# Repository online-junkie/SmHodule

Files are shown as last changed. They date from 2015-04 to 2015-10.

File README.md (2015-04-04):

# SmHodule

SmHodule is using the Wifi SoC ESP8266, the ESP8266 is a System on Chip and is as powerful as an Arduino.

SmHodule = Smart Home module for the Internet of Things.

This module is based on a set of examples found in the Internet about ESP8266 and implementing a actor, sender, sensor and I2C OLED.

The Setup data is cached in the modules flash memory.

Feel free to expand SmHodule and add your own ideas.

## Compile

Compile the code, then: make clean, make html, make all, make flashall
 
For first time setup keep GPIO15 pulled to ground for 35 seconds.
After first time configuration the module reboots and starts as an Access Point. Connect your wifi network to the new AP and use the default AP IP: 192.168.4.1 in your browser to access the module. Note: Your local router has to be DHCP enabled.

The device MAC and also the IP the module receives is shown on the SmHodule setup page. Make this IP static DHCP by using the modules name as the device name for your DHCP configuration.

Enjoy

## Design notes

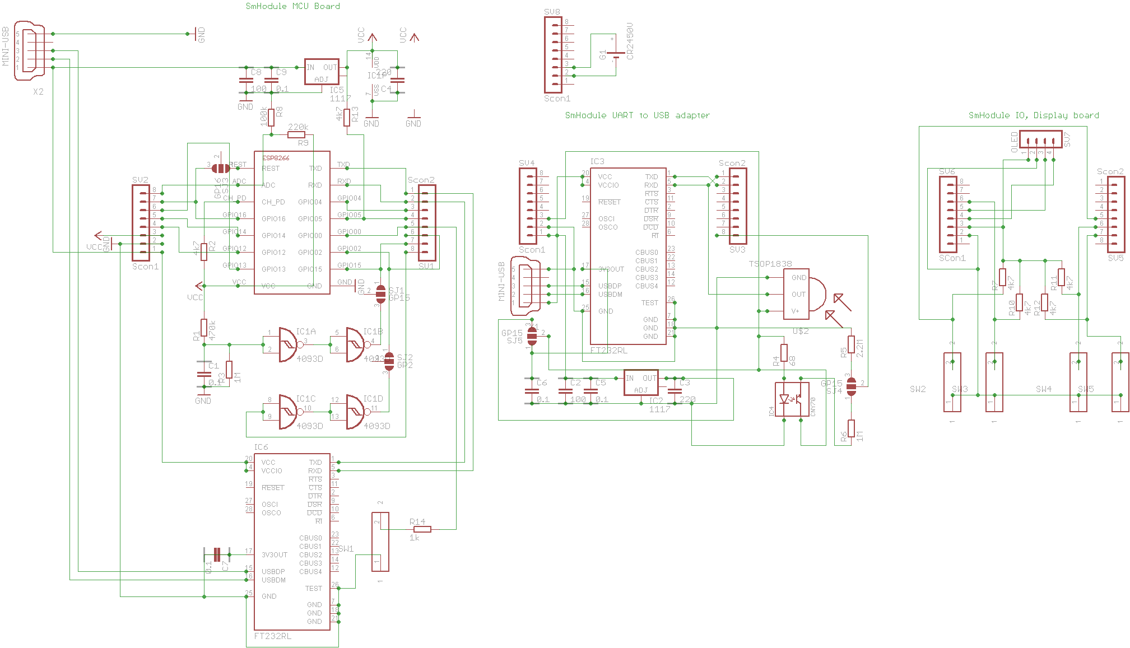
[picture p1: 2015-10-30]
SmHodule/SmHodule-Schematic.png

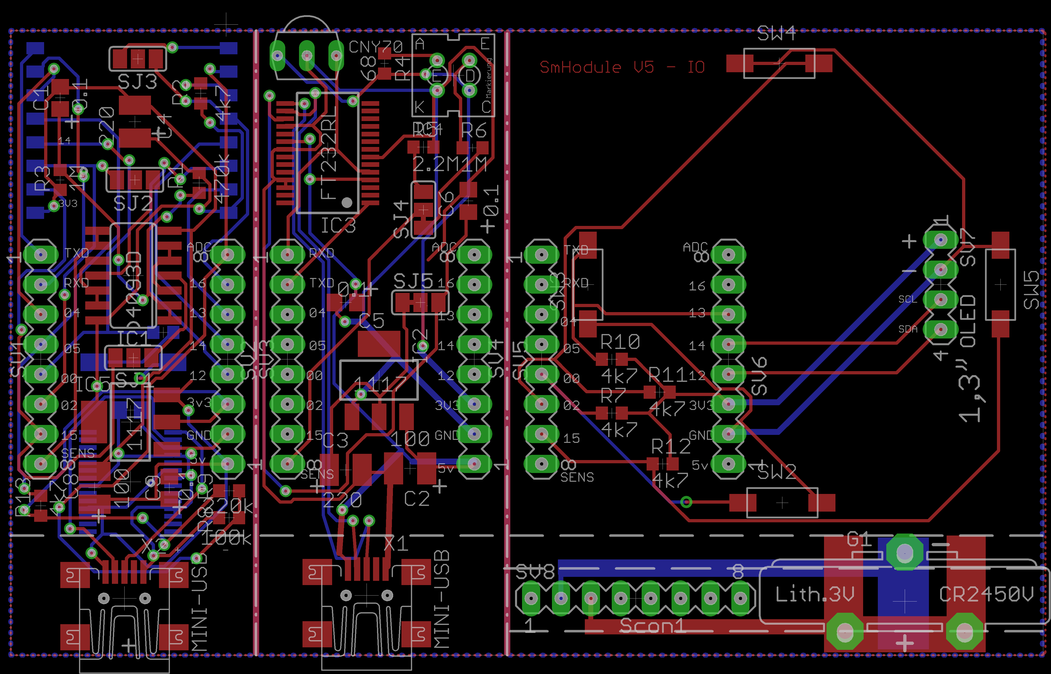
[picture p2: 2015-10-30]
SmHodule/SmHodule.png

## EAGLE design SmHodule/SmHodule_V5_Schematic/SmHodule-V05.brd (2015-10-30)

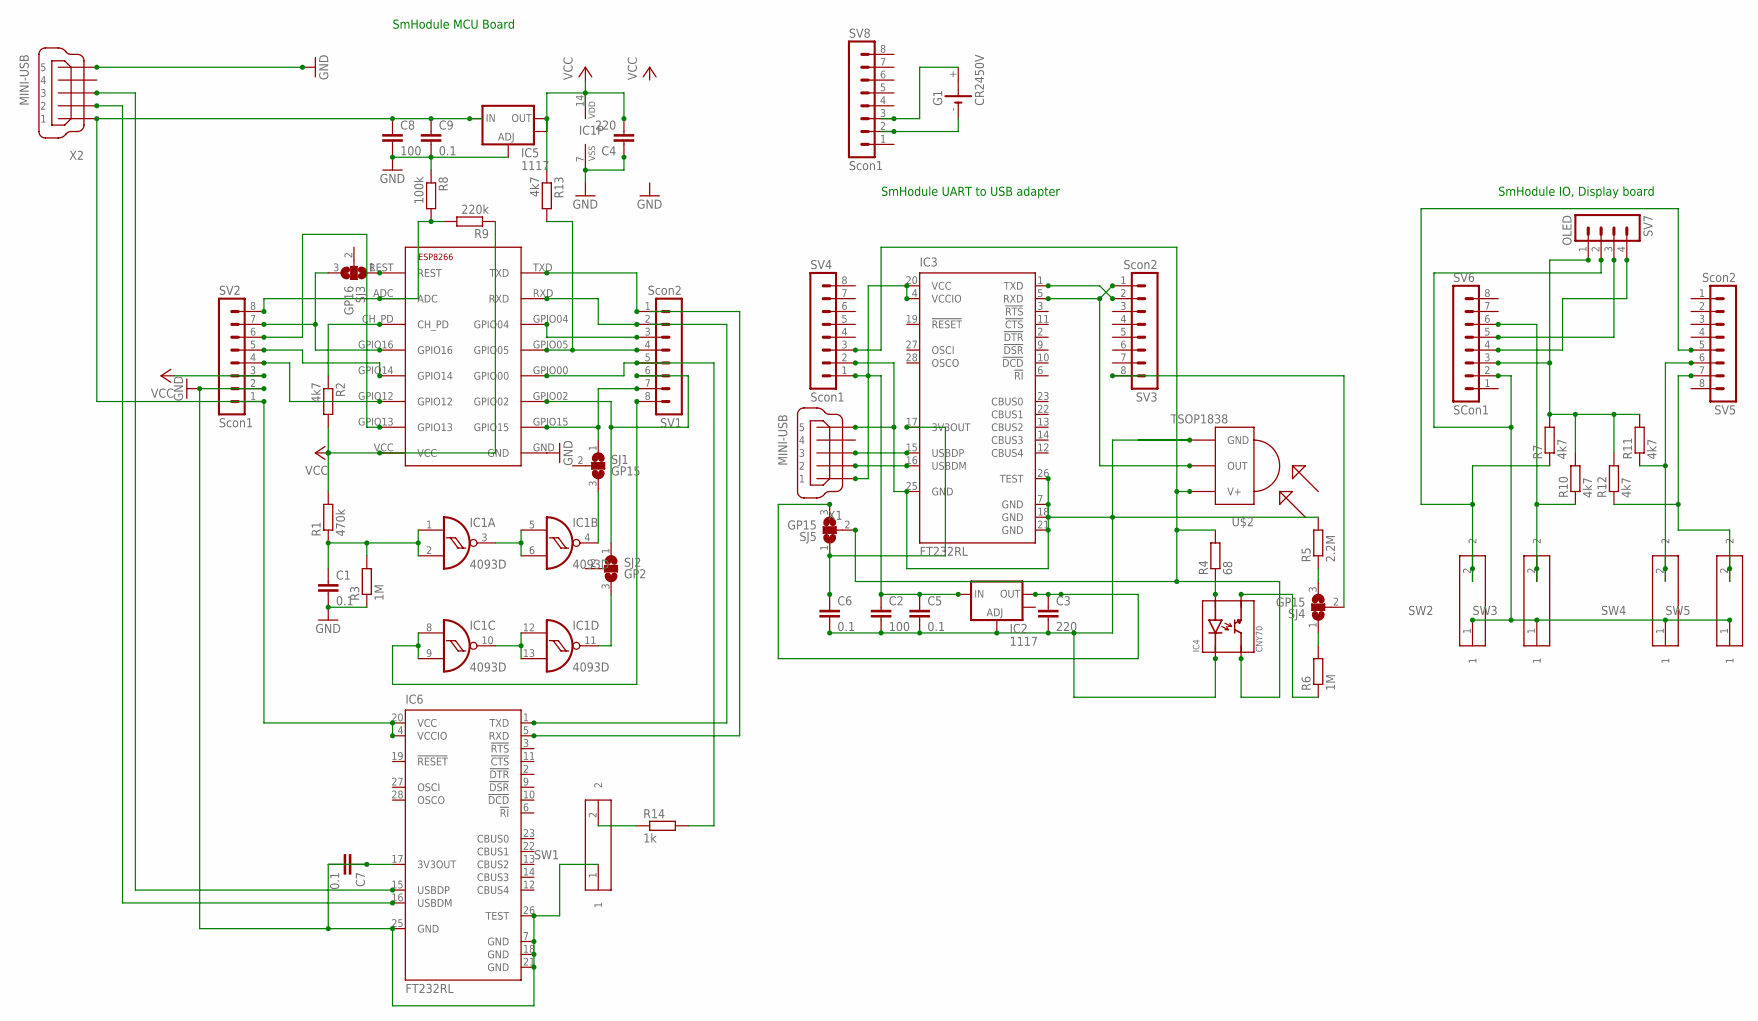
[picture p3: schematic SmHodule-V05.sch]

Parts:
C1, C5, C6, C7, C9: 0.1; C0805
C2, C8: 100; C1210
C3, C4: 220; C1210
G1: CR2450V
IC1: 4093D; SO14
IC2, IC5: 1117; SOT223
IC3, IC6: FT232RL; SSOP28
IC4: CNY70
R1: 470k; R0603
R2, R7, R10, R11, R12, R13: 4k7; R0603
R3, R6: 1M; R0603
R4: 68; R0603
R5: 2.2M; R0603
R8: 100k; R0603
R9: 220k; R0603
R14: 1k; R0603
SJ1, SJ4, SJ5: GP15; SJ_2
SJ2: GP2; SJ_2
SJ3: GP16; SJ_2
SV1, SV3, SV5: Scon2; MA08-1
SV2, SV4, SV8: Scon1; MA08-1
SV6: SCon1; MA08-1
SV7: OLED; MA04-1
SW1, SW2, SW3, SW4, SW5: 434111043826
U$1: ESP1; ESP-12
U$2: TSOP1838; TSOP18XX
X1, X2: MINI-USB; UX60-MB-5ST

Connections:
GND: C1.2, C4.1, C7.2, C8.2, C9.2, IC1.7 (VSS), IC5.1 (ADJ), IC6.7 (GND), IC6.18 (GND), IC6.21 (GND), IC6.25 (GND), IC6.26 (TEST), R3.1, R8.1, SV2.2, SW1.1, U$1.GND, X2.5
unnamed: C1.1, IC1.1 (I0), IC1.2 (I1), R1.1, R3.2
unnamed: IC1.3 (O), IC1.5 (I0), IC1.6 (I1)
unnamed: IC3.1 (TXD), SV3.2
unnamed: IC1.10 (O), IC1.12 (I0), IC1.13 (I1)
unnamed: IC1.4 (O), SJ1.3
unnamed: SV1.1, U$1.TXD
unnamed: SV1.2, U$1.RXD
unnamed: SV2.6, U$1.GPIO13
unnamed: R14.2, SV1.5, U$1.GPIO00
unnamed: SV2.4, U$1.GPIO12
unnamed: SV2.5, U$1.GPIO14
unnamed: SV1.3, U$1.GPIO04
unnamed: R13.2, SV1.4, U$1.GPIO05
unnamed: SJ3.3, SV2.7, U$1.GPIO16
unnamed: R6.2, SJ4.1
unnamed: R8.2, R9.2, SV2.8, U$1.ADC
unnamed: R2.1, U$1.CH_PD
unnamed: SJ1.1, SV1.7, U$1.GPIO15
unnamed: IC3.5 (RXD), SV3.1, U$2.OUT
unnamed: C2.2, C3.2, C5.2, C6.2, IC2.1 (ADJ), IC3.7 (GND), IC3.18 (GND), IC3.21 (GND), IC3.25 (GND), IC3.26 (TEST), IC4.EK, R5.2, SV4.2, U$2.GND, X1.5
unnamed: IC1.11 (O), SJ2.3
unnamed: SJ2.1, SV1.6, U$1.GPIO02
unnamed: SJ3.1, U$1.REST
unnamed: IC1.8 (I0), IC1.9 (I1), SV1.8
unnamed: IC4.DC, R4.2, SJ5.2, SV4.3, U$2.VCC (V+)
unnamed: C2.1, C5.1, IC2.3 (IN), IC3.4 (VCCIO), IC3.20 (VCC), SV4.1, X1.1
unnamed: R7.2, R10.2, R11.2, R12.2, SV6.3, SV7.1
unnamed: R11.1, SV5.6, SW4.2
unnamed: IC4.DE, R6.1
unnamed: R5.1, SJ4.3
unnamed: SV6.5, SV7.3
unnamed: R10.1, SV6.6, SW3.2
unnamed: R14.1, SW1.2
unnamed: IC4.EA, R4.1
unnamed: IC3.16 (USBDM), X1.2
unnamed: IC3.15 (USBDP), X1.3
unnamed: C6.1, IC3.17 (3V3OUT), SJ5.1
unnamed: R7.1, SV5.5, SW2.2
unnamed: SV6.4, SV7.4
unnamed: R12.1, SV5.7, SW5.2
unnamed: C3.1, IC2.2 (OUT), SJ5.3
unnamed: SV6.2, SV7.2, SW2.1, SW3.1, SW4.1, SW5.1
unnamed: SJ4.2, SV3.8
unnamed: G1.-, SV8.2
unnamed: G1.+, SV8.3
unnamed: C8.1, C9.1, IC5.3 (IN), IC6.4 (VCCIO), IC6.20 (VCC), SV2.1, X2.1
unnamed: IC6.15 (USBDP), X2.3
unnamed: IC6.16 (USBDM), X2.2
unnamed: C7.1, IC6.17 (3V3OUT)
VCC: C4.2, IC1.14 (VDD), IC5.2 (OUT), IC5.4 (OUT), R1.2, R2.2, R9.1, R13.1, SV2.3, U$1.VCC

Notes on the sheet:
SmHodule MCU Board
SmHodule UART to USB adapter
SmHodule IO, Display board

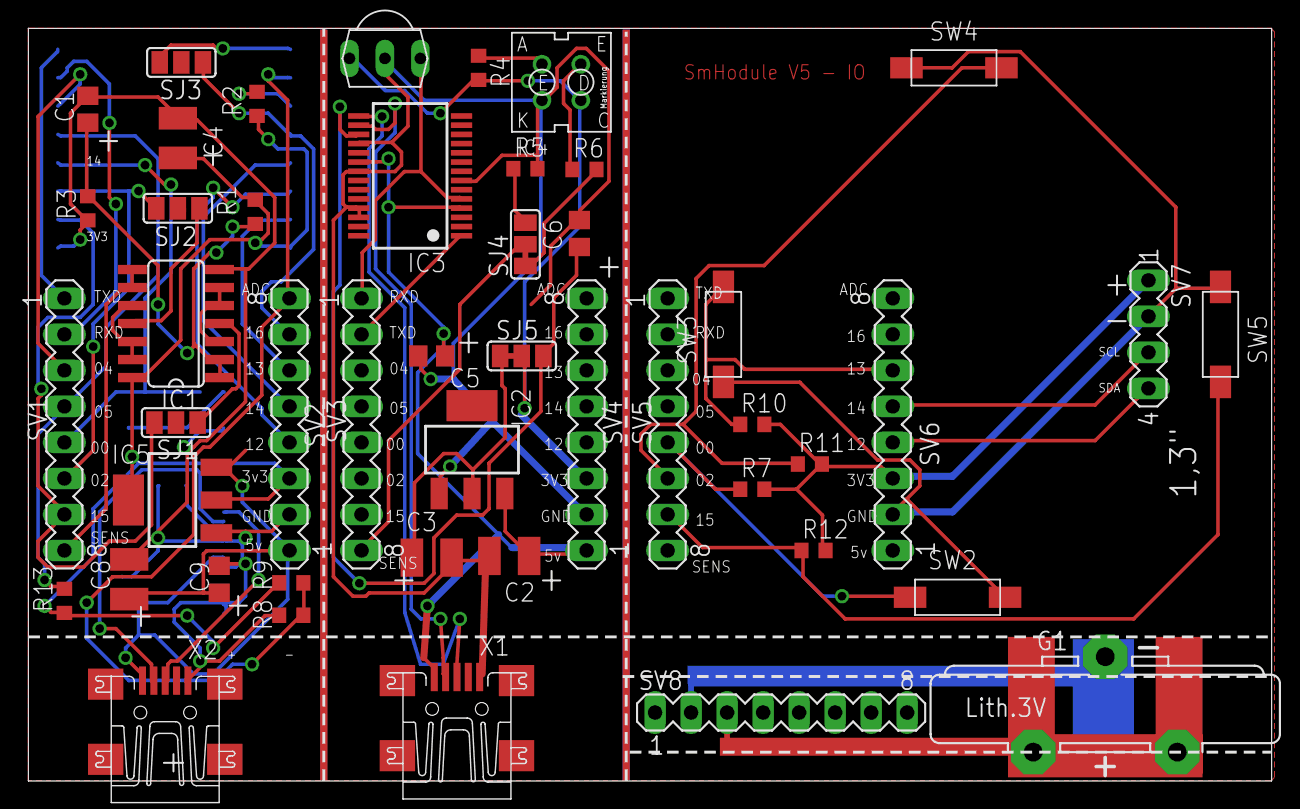
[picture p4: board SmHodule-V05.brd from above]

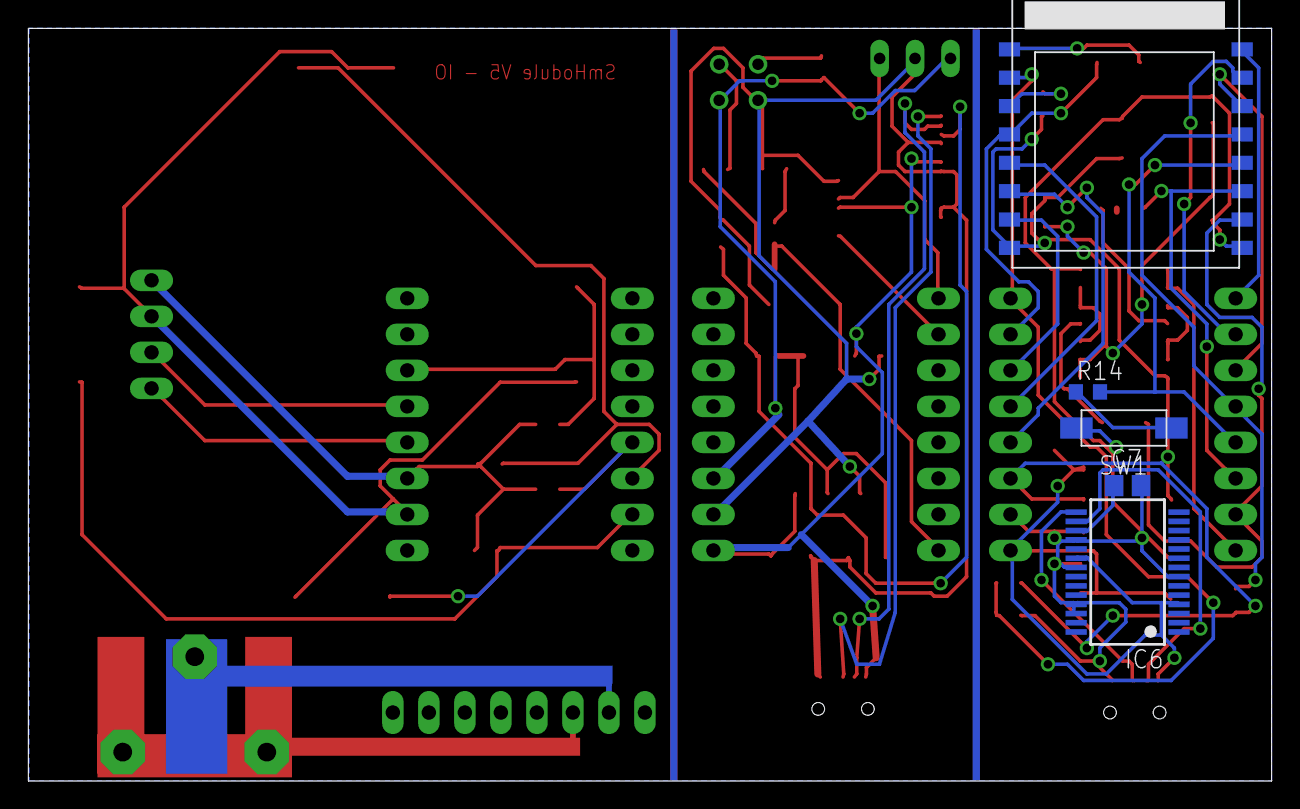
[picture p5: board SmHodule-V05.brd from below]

Board: 2 copper layers, 87.7 x 53.1 mm, 52 parts (5 on the bottom side), 51 nets.

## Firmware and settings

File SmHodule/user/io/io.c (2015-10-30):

/*
 * ----------------------------------------------------------------------------
 * "THE BEER-WARE LICENSE" (Revision 42):
 * Jeroen Domburg <jeroen@spritesmods.com> wrote this file. As long as you retain 
 * this notice you can do whatever you want with this stuff. If we meet some day, 
 * and you think this stuff is worth it, you can buy me a beer in return. 
 * ----------------------------------------------------------------------------
 */


#include "c_types.h"
#include "user_interface.h"
#include "espconn.h"
#include "mem.h"
#include "osapi.h"
#include "gpio.h"
#include "io/gpio16.h"
#include "wifi/wifi.h"
#include "espmissingincludes.h"
#include "smhodule.h"
#include "io/io.h"
#include "i2c/i2c.h"
#include "i2c/i2c_oled.h"
#include "i2c/i2c_bmp180.h"

#define BTNDOWNGPIO 15
#define BTNUPGPIO 13
#define BTNRIGHTGPIO 2
#define BTNLEFTGPIO 0

static volatile bool OLED;
static ETSTimer resetBtnDwntimer;
static ETSTimer resetBtnUptimer;
static ETSTimer resetBtnLefttimer;
static ETSTimer resetBtnRighttimer;
static int fontsize = 2;
uint32 stime0 = 0, stime1 = 0;
static uint16_t gpio13_counter = 0;                        // gpio13 counter

void ICACHE_FLASH_ATTR ioGPIO16(int ena) {
	if (ena) {
		gpio16_output_set(1);
		if ( atoi(Setup.OLED) == 1 )
			OLED_Print(1,(1*fontsize),"GPIO16:on ",fontsize); // x,y,text,fontsize -> y need to be 2*fontsize
	} else {
		gpio16_output_set(0);
		if ( atoi(Setup.OLED) == 1 )
			OLED_Print(1,(1*fontsize),"GPIO16:off",fontsize);
	}
}

static void ICACHE_FLASH_ATTR resetBtnUpTimerCb(void *arg) {
	static int resetCnt=0;
	if (!GPIO_INPUT_GET(BTNUPGPIO)) {
		resetCnt++;
		os_printf("UP Cnt: %d\n", resetCnt);
	} else {
		if (resetCnt>=3 ) { //>200msec pressed
			sendKeyData(2,resetCnt,1); // long
			os_printf("Key UP pressed long\n");
		} else if (resetCnt>=1 && resetCnt <=2 ) { //<200msec pressed
			sendKeyData(2,0,1); //short
			os_printf("Key UP pressed short\n");
		}
		resetCnt=0;
	}
}

static void ICACHE_FLASH_ATTR resetBtnLeftTimerCb(void *arg) {
	static int resetCnt=0;
	if (!GPIO_INPUT_GET(BTNLEFTGPIO)) {
		resetCnt++;
		os_printf("Left cnt: %d\n", resetCnt);
	} else {
		if (resetCnt > 40) { //>8 sec pressed and clear config
			setup_wifi_ap_mode();
			initSetupData();
		} else if (resetCnt>=3 && resetCnt<=40) { //<8 sec pressed
			sendKeyData(4,resetCnt,2); // long
			os_printf("Key Left pressed long\n");
		} else if (resetCnt>=1 && resetCnt <=2 ) { //<200msec pressed
			sendKeyData(4,0,2); //short
			os_printf("Key Left pressed short\n");
		}
		resetCnt=0;
	}
}

static void ICACHE_FLASH_ATTR resetBtnRightTimerCb(void *arg) {
	static int resetCnt=0;
	if (!GPIO_INPUT_GET(BTNRIGHTGPIO)) {
		resetCnt++;
		os_printf("Right cnt: %d\n", resetCnt);
	} else {
		if (resetCnt>=3) { //>200msec pressed
			sendKeyData(3,resetCnt,3); // long
			os_printf("Key RIGHT pressed long\n");
		} else if (resetCnt>=1 && resetCnt <=2 ) { //<200msec pressed
			sendKeyData(3,0,3); //short
			os_printf("Key RIGHT pressed short\n");
		}
		resetCnt=0;
	}
}

static void ICACHE_FLASH_ATTR resetBtnDwnTimerCb(void *arg) {
	static int resetCnt=0;
	if (!GPIO_INPUT_GET(BTNDOWNGPIO)) {
		resetCnt++;
		os_printf("DOWN resetCnt: %d\n", resetCnt);
	} else {
		if (resetCnt>=3) { //>=200msec pressed
			sendKeyData(1,resetCnt,0); // long
			os_printf("Key DOWN pressed long\n");
		} else if (resetCnt>=1 && resetCnt <=2 ) { //<200 msec pressed
			sendKeyData(1,0,0); //short
			os_printf("Key DOWN pressed short\n");
		}
		resetCnt=0;
	}
}

static void ICACHE_FLASH_ATTR gpio13_int_handler(int8_t key) // key not right used
{
	ETS_GPIO_INTR_DISABLE();  										// Disable gpio interrupts
	// Increment counter
    gpio13_counter++;
    //Not that sure what this does yet and where the register is used for
    uint32 gpio_status = GPIO_REG_READ(GPIO_STATUS_ADDRESS);
    //clear interrupt status
    GPIO_REG_WRITE(GPIO_STATUS_W1TC_ADDRESS, gpio_status & BIT(key));
    ETS_GPIO_INTR_ENABLE();                                         // Enable gpio interrupts
}

void ICACHE_FLASH_ATTR gpio13_int_prepare(void)
{
	// prepare GPIO13 to handle interrupts
	ETS_GPIO_INTR_DISABLE();  										// Disable gpio interrupts
	ETS_GPIO_INTR_ATTACH(gpio13_int_handler, 13);                   // GPIO13 interrupt handler
	PIN_FUNC_SELECT(PERIPHS_IO_MUX_MTCK_U, FUNC_GPIO13);            // Set GPIO13 function
	gpio_output_set(0, 0, 0, GPIO_ID_PIN(13));                       // Set GPIO13 as input
	GPIO_REG_WRITE(GPIO_STATUS_W1TC_ADDRESS, BIT(13));               // Clear GPIO13 status
	gpio_pin_intr_state_set(GPIO_ID_PIN(13), GPIO_PIN_INTR_POSEDGE); // Interrupt on GPIO13
	PIN_PULLUP_DIS(PERIPHS_IO_MUX_MTCK_U);                          // Disabe pullup
	ETS_GPIO_INTR_ENABLE();                                         // Enable gpio interrupts
}

uint16_t ICACHE_FLASH_ATTR getGpio13Counter(void) {
	return gpio13_counter;
}

void ICACHE_FLASH_ATTR resetGpio13Counter(void) {
	gpio13_counter = 0;
}

void ioInit() {
	bool isInitialized = 0;
	gpio_init();
	// validate if possible because during boot GPIO0 and GPIO15 need to be low level

    // 12 and 14 should be used for I2C bus
	// this are the two pins we're going to use
    // gpio12 (sda), 14 (scl) are used as i2c
	if ( atoi(Setup.OLED) == 1 ) {
		i2c_init();
		isInitialized = 1;
		OLED = OLED_Init();
		OLED_Print(0, 0, getSmHoduleName(), fontsize);
	}
	if ( atoi(Setup.BMP180) == 1 ) {
		if ( !isInitialized)
			i2c_init();
		BMP180_Init();
	}
	// dangerous, use only if gpio16 is not bridged with rst
	// use this module as an actor
	if ( atoi((uint8_t *) Setup.Type) >= 3 ) {
		// SmHodule is used as an actor -> GPIO16
		gpio16_output_conf();
		gpio16_output_set(0);
	} else if ( atoi((uint8_t *) Setup.Type) == 2 ) {
		// SmHodule is used as a sender...
		//gpio16_output_set(1);

		// Key Right GPIO2
		PIN_FUNC_SELECT(PERIPHS_IO_MUX_GPIO2_U, FUNC_GPIO2);
		os_timer_disarm(&resetBtnRighttimer);
		os_timer_setfn(&resetBtnRighttimer, resetBtnRightTimerCb, NULL);
		os_timer_arm(&resetBtnRighttimer, 100, 1);

		// Key Up GPIO13
		PIN_FUNC_SELECT(PERIPHS_IO_MUX_MTCK_U, FUNC_GPIO13);
		os_timer_disarm(&resetBtnUptimer);
		os_timer_setfn(&resetBtnUptimer, resetBtnUpTimerCb, NULL);
		os_timer_arm(&resetBtnUptimer, 100, 1);

		// Key Left GPIO0
		PIN_FUNC_SELECT(PERIPHS_IO_MUX_GPIO0_U, FUNC_GPIO0);
		os_timer_disarm(&resetBtnLefttimer);
		os_timer_setfn(&resetBtnLefttimer, resetBtnLeftTimerCb, NULL);
		os_timer_arm(&resetBtnLefttimer, 100, 1);
	} else {
		// SmHodule is used as a sensor
		// if used as a sensor, then gpio13 is used to count events
		// basically a 10sec measurement and then value is send to host
		gpio13_int_prepare();  // for interrupt
	}

	// By default GPIO 15 is used to reset module incl. wifi
	//key Dwn GPIO15
	PIN_FUNC_SELECT(PERIPHS_IO_MUX_MTDO_U, FUNC_GPIO15);
	os_timer_disarm(&resetBtnDwntimer);
	os_timer_setfn(&resetBtnDwntimer, resetBtnDwnTimerCb, NULL);
	os_timer_arm(&resetBtnDwntimer, 100, 1);
}

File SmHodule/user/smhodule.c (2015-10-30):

/*
 * msg_handler.c
 *
 *  Created on: 30.01.2015
 *      Author: K4546
 */

#include <string.h>
#include <osapi.h>
#include "user_interface.h"
#include "mem.h"
#include "http/httpd.h"
#include "cgi/cgi.h"
#include "io/io.h"
#include "ip/TcpClient.h"
#include "spi_flash.h"
#include "smhodule.h"
#include "espmissingincludes.h"
//#include "mqtt/mqtt.h"

#define FLASHSECTOR 0x3A
#define FLASHSECTOROLED 0x3C
SETUPDATA Setup;
OLEDDATA Oled;

char payload[1024];

//MQTT_Client mqttClient;
static char pheadbuffer[] = "Connection: close\r\n\r\n";

/*
static char pheadbuffer[] = "Keep-Alive: 5\r\n\
Connection: keep-alive\r\n\
Accept: text/html\r\n\
User-Agent: Mozilla/5.0 (SmHodule)\r\n\r\n";
*/
/*
static void ICACHE_FLASH_ATTR nop_cb(void) {
	os_printf("nop_cb\r\n");
}
*/

static void ICACHE_FLASH_ATTR sleep_cb(void) {
	os_printf("sleep_cb\r\n");
	if ( (atoi((uint8_t *) Setup.Interval) > 0) && (atoi((uint8_t *) Setup.Type) == 1)) {
		// if used as a Sender then we can use deep-sleep to save power, acting as a receiver or Permanent then skip deep sleep
		// GPIO 16 has to be connected to RST for making deep_sleep work.
		system_deep_sleep(atoi((uint8_t *) Setup.Interval)*60*1000*1000);
	}
}

static void ICACHE_FLASH_ATTR createPayload( int count, char * ip ) {
	char hostdata[480];
    if ( count < 0 ) {
    	count = getGpio13Counter();
    	resetGpio13Counter();
    }
    	os_sprintf(hostdata,"HTTP/1.0\r\nHost: %s\r\n%s",ip,pheadbuffer);
    	switch (atoi((char *) Setup.DPType)) {
    	case 1: // HM: http://IP_DER_ZENTRALE:8181/test.exe?x=dom.GetObject('BidCos-RF.SERIENNUMMER:1.STATE').State(1);
    		os_sprintf(payload, "GET /execute.exe?x=dom.GetObject(\"%s\").Value(%d) %s",(uint8_t *) Setup.DP,count,hostdata);
    		break;
    	case 2: //CCUIO: http://ccu-io-host:ccu.io-port/api/set/950/?value=1
    		os_sprintf(payload, "GET /api/set/%s/?value=%d %s",(uint8_t *) Setup.DP,count,hostdata);
    		break;
    	case 3: // IOBroker: http://ip:8087/set/hm-rpc.0.IEQ12345.LEVEL?user=admin&pass=iobroker?value=1&prettyPrint
    		if ( os_strlen((uint8_t *) Setup.User) > 0 ) {
    			os_sprintf(payload, "GET /set/%s?user=%s&pass=%s?value=%d&prettyPrint %s",(uint8_t *) Setup.DP,count,hostdata);
    		} else {
    			os_sprintf(payload, "GET /set/%s?value=%d&prettyPrint %s",(uint8_t *) Setup.DP,count,hostdata);
    		}
    		break;
    	case 4: // NATIVE: http://IP:PORT/irgendetwas/DataPointer/Val=%VALUE%
     		os_sprintf(payload,"GET /%s%d %s",(uint8_t *) Setup.DP,count,hostdata);
    		break;
    	case 5: // MQTT
    		break;
    }
}

void ICACHE_FLASH_ATTR sendStatus(int i) {
	//if ( blocked == 0 ) {
    	if ( os_strlen(Setup.IP) > 0 ) {
    		os_printf("Sending status\n");
    		ETS_GPIO_INTR_DISABLE();
    		createPayload(i, (uint8_t *) Setup.IP);
    		os_printf(payload);
    	    TcpSend(TCP, (uint8_t *) Setup.IP, atoi((uint8_t *) Setup.Port),payload, NULL);
        	ETS_GPIO_INTR_ENABLE();
    	}
	//}
}
//send data to switch
void ICACHE_FLASH_ATTR sendKeyData(int key, int duration, int mode) {

	char payload[1024];
	int id;
	static int lastvalue[10] = {0,0,0,0,0,0,0,0,0,0};
	lastvalue[key] = ( lastvalue[key] ) ? 0 : 1;
	lastvalue[key+1] = duration;
	os_sprintf(payload, "GET /api/set?switch=1&key=%d&duration=%d&mode=%d HTTP/1.0\r\nHost:",lastvalue[key],key,lastvalue[key+1],mode);
//	if ( blocked == 0 ) {
    	ETS_GPIO_INTR_DISABLE();
    		if ( os_strlen(Setup.AIP) > 0 ) {
    			os_sprintf(payload, "%s %s\r\n%s",payload,(uint8_t *) Setup.AIP,pheadbuffer);
    			os_printf(payload);
    			TcpSend(TCP, (uint8_t *) Setup.AIP, atoi((uint8_t *) Setup.APort), payload, NULL);
    		}
    	ETS_GPIO_INTR_ENABLE();
//    }
}

// send data to Host
static void ICACHE_FLASH_ATTR sendData(void *arg) {
//    if ( blocked == 0 ) {
/*    	response if ccu.io
 * 		{
    	  "100015": {
    	    "val": 50,
    	    "ts": "2015-03-03 23:04:19"
    	  }
    	} */
    	if ( os_strlen(Setup.IP) > 0 ) {
    		ETS_GPIO_INTR_DISABLE();
    		createPayload(-1, (uint8_t *) Setup.IP);
    		os_printf(payload);
    		TcpSend(TCP, (uint8_t *) Setup.IP, atoi((uint8_t *) Setup.Port), payload, sleep_cb);
    		ETS_GPIO_INTR_ENABLE();
    	}
//    }
}

void ICACHE_FLASH_ATTR readConfig( void ) {
	spi_flash_read((SPI_FLASH_SEC_SIZE * FLASHSECTOR), (uint32 *)&Setup, sizeof(SETUPDATA));
}

void ICACHE_FLASH_ATTR resetPermMode( void ) {
	spi_flash_read((SPI_FLASH_SEC_SIZE * FLASHSECTOR), (uint32 *)&Setup, sizeof(SETUPDATA));
	os_strcpy((uint8_t *) Setup.Interval, "0");
	saveConfig();
}

void ICACHE_FLASH_ATTR saveConfig() {
	//os_printf("Saving: %s-%s-%s-%s-%s-%s-%s-%s-%s-%s-%s-%s\r\n",(uint8_t *) Setup.DPType,(uint8_t *) Setup.DP,(uint8_t *) Setup.IP,(uint8_t *) Setup.Port,(uint8_t *) Setup.AIP,(uint8_t *) Setup.APort,(uint8_t *) Setup.Auth,(uint8_t *) Setup.Interval,(uint8_t *) Setup.User,(uint8_t *) Setup.Pass,(uint8_t *) Setup.Type,(uint8_t *) Setup.Device);
	os_timer_disarm(&smhodule_timer);
	os_printf("saving config to flash\n");
	ETS_GPIO_INTR_DISABLE();
	ETS_UART_INTR_DISABLE();
	spi_flash_erase_sector(FLASHSECTOR);
	spi_flash_write((SPI_FLASH_SEC_SIZE * FLASHSECTOR), (uint32 *)&Setup, sizeof(SETUPDATA));
	ETS_UART_INTR_ENABLE();
	ETS_GPIO_INTR_ENABLE();
	os_timer_arm(&smhodule_timer, (seconds * 1000), 1);
}

// normal system startup
void smhoduleInit (void ) {
	readConfig();
//try at higher cpu speed.
//	REG_SET_BIT(0x3ff00014, BIT(0));
//    os_update_cpu_frequency(160);
//    REG_CLR_BIT(0x3ff00014, BIT(0));
//    os_update_cpu_frequency(80);

#ifdef PLATFORM_DEBUG
	os_printf("max heap available: %u\r\n",system_get_free_heap_size());
#endif
	if ( atoi((uint8_t *) Setup.DPType) == 5 ) {
		// MQTT
		//mqtt_init();
	} else {
		ioInit();
		if ( atoi((uint8_t *) Setup.Type) == 1 ) {
			os_printf("SmHodule is acting as a sensor %d\n", seconds);
			os_timer_disarm(&smhodule_timer);
			os_timer_setfn(&smhodule_timer, sendData, NULL); // set the timer function, dot get os_timer_func_t to force function convert
			os_timer_arm(&smhodule_timer, (seconds * 1000), 1);
		} else if  (atoi((uint8_t *) Setup.Type) == 2 ) {
			os_printf("SmHodule is acting as a control\n");
		} else {
			os_printf("SmHodule is acting as an actor\n");
		}
	}
}

//os_sprintf(sysCfg.mqtt_user, "%s", MQTT_USER);
void ICACHE_FLASH_ATTR initSetupData( void ) {
	// only on first time setup or when wifi is reset
	os_timer_disarm(&smhodule_timer);
	os_printf("flush config\n");
	ETS_GPIO_INTR_DISABLE();
	ETS_UART_INTR_DISABLE();
	spi_flash_erase_sector(FLASHSECTOR);
	ETS_UART_INTR_ENABLE();
	ETS_GPIO_INTR_ENABLE();
	os_timer_arm(&smhodule_timer, (seconds * 1000), 1);
	spi_flash_read((SPI_FLASH_SEC_SIZE * FLASHSECTOR), (uint32 *)&Setup, sizeof(SETUPDATA));
	os_sprintf((uint8_t *) Setup.Device, "%s", (uint8_t *) getSmHoduleName());
	os_strcpy((uint8_t *) Setup.WifiApPassword, (uint8_t *) "00000000");
	os_strcpy((uint8_t *) Setup.WifiStPassword, (uint8_t *) "00000000");
	saveConfig();
}

void ICACHE_FLASH_ATTR getSetupData() {
	readConfig();
}
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

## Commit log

2015-08-15 Minor fixes - first init, defaults name to SmHodul-<mac>
    [io.c, smhodule.c]
2015-08-16 Solved problem with TcpClient closing connection
    [io.c, smhodule.c]
2015-08-16 Fix for Display board, keys are now in reverse but correct order.
    [io.c, smhodule.c]
2015-10-30 Eagle files
    [SmHodule-V05.brd, SmHodule-V05.sch]

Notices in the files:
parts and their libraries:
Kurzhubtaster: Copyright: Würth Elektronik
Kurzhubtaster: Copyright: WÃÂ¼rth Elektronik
